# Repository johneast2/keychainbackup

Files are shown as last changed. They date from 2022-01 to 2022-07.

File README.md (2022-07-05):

# keychainbackup



## What is keychainbackup?

Keychain backup is a simple device to create encrypted backups of your files that you take with you on your keychain! Think of it as an offsite backup of your important files, that is always with you. With the added benfit of not having to pay monthly fees.

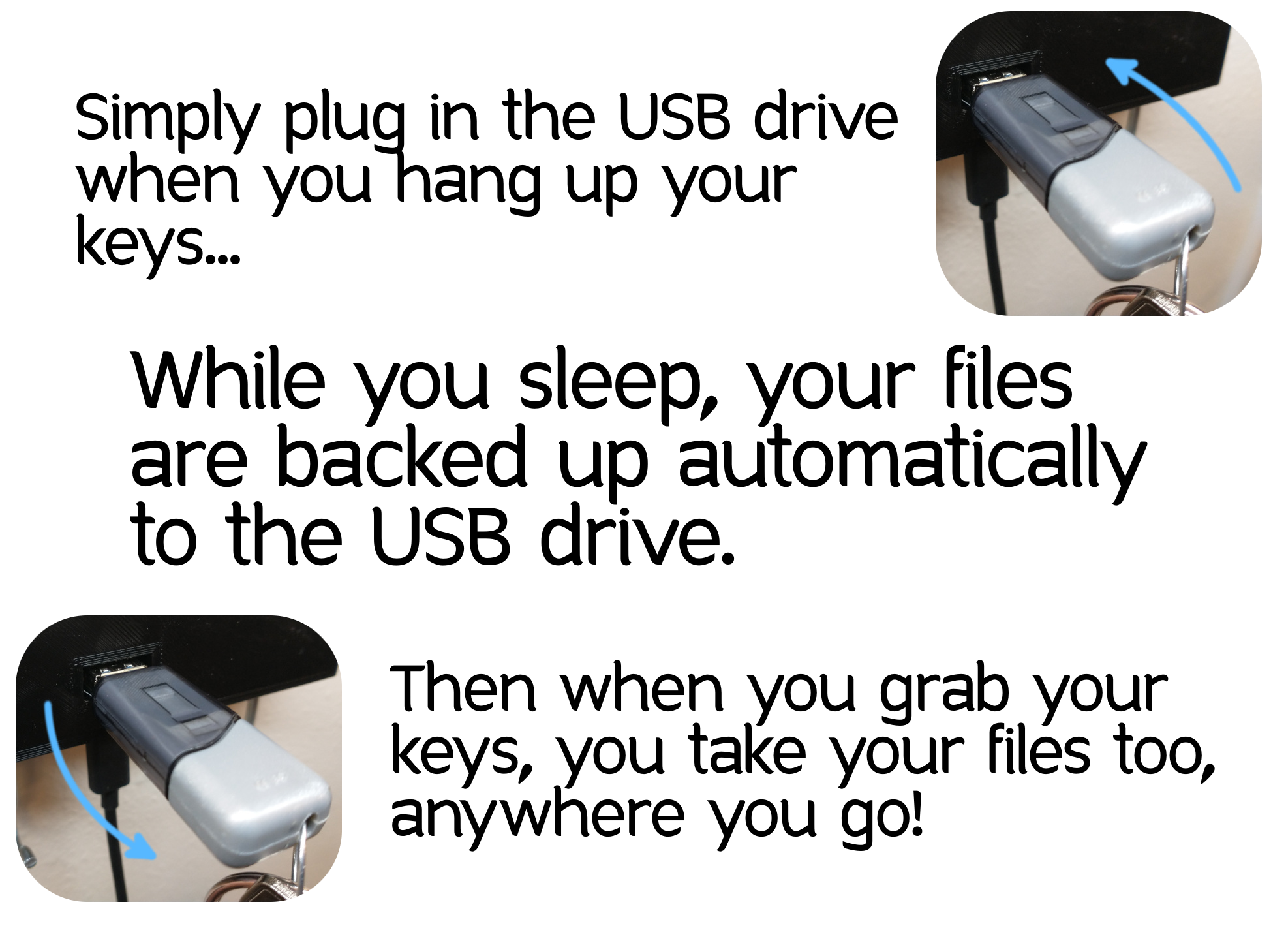
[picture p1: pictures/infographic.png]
infographic


## Example setups

Here's some examples of how to use keychain backup. Personally, I have a linux server that acts as a backup server. My important files from my other computers get backed up to it, then every night it backs up the changed files to the keychain backup. I have it scheduled to stop running the backup early in the morning, to make sure that the USB flash drive can be removed safely.

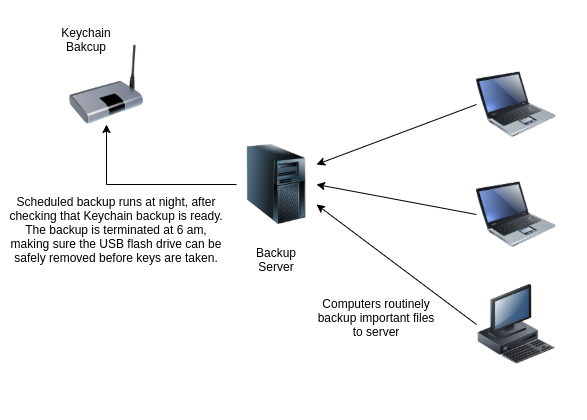
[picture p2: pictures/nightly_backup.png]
nightly backup


Another idea I had was to alternate USB flash drives. That would allow backups to run during the day without an extra backup server.

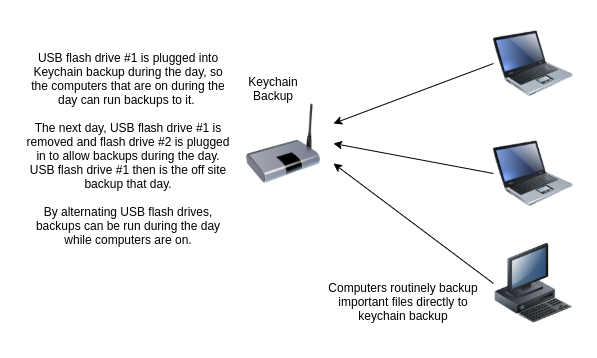
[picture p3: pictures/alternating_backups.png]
Alternating backups


## Questions and Answers

Q: Since I can't do "Safely Remove USB" on my USB drive, won't the filesystem on my USB drive get ruined?

A: It is designed to use the ext4 filesystem, which is a very resisilent. To prove that, I created a test system to mimic unexpectedly removing the USB Drive. It tested 500+ removals and had no failures! You can read about it [here.](docs/TestingResults.md)

## Getting Started

### Raspberry Pi Version

JUN 16 2022 - Still a work in progress. These steps should work to get you setup but there may be bugs! John

### Hardware Setup

Items needed:

1x printed out case - get it [here](case/raspberry_pi_case.stl)

4x m2.5 5mm screws (for mounting the raspberry pi in the case)

3x cup hooks (I used 1.25" Hillman Cup hooks)

2x #8 2.5" screws (for mounting on the wall)

2x drywall screw holders (also for mounting on the wall)

Drill with 1/4" drill bit (for the drywall holder screw holes)

1x Raspberry Pi, setup to connect to your wifi + its power stuff

USB Drive formatted with EXT4 for backing up to.

1. Place the Raspberry Pi in the case and screw it in with the 4x m2.5 screws.

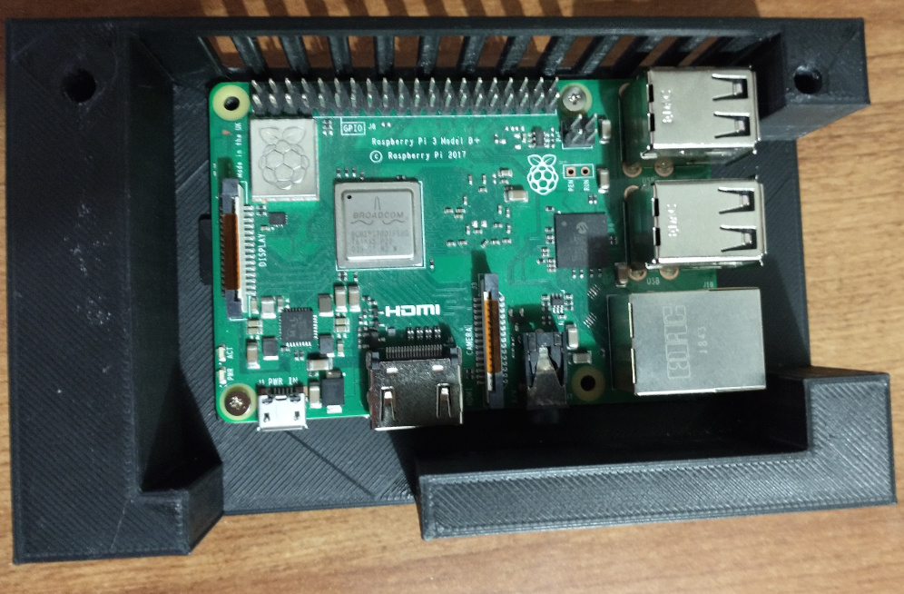
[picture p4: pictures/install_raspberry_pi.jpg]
installing into case


2. Screw in the cup hooks to the bottom of the case.

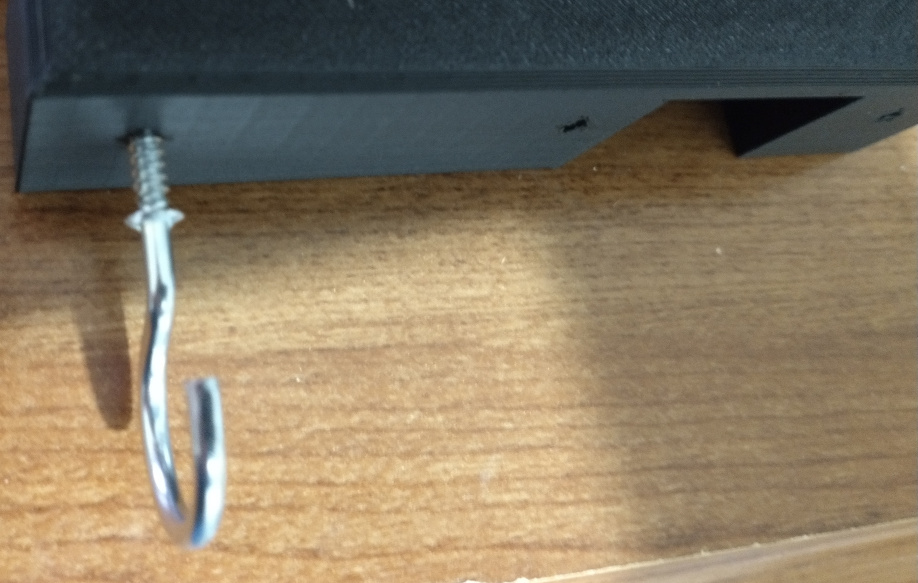
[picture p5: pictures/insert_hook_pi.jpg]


3. Using the case as a guide, drill out 1/4" holes and mount the case with the 2x #8 screws.

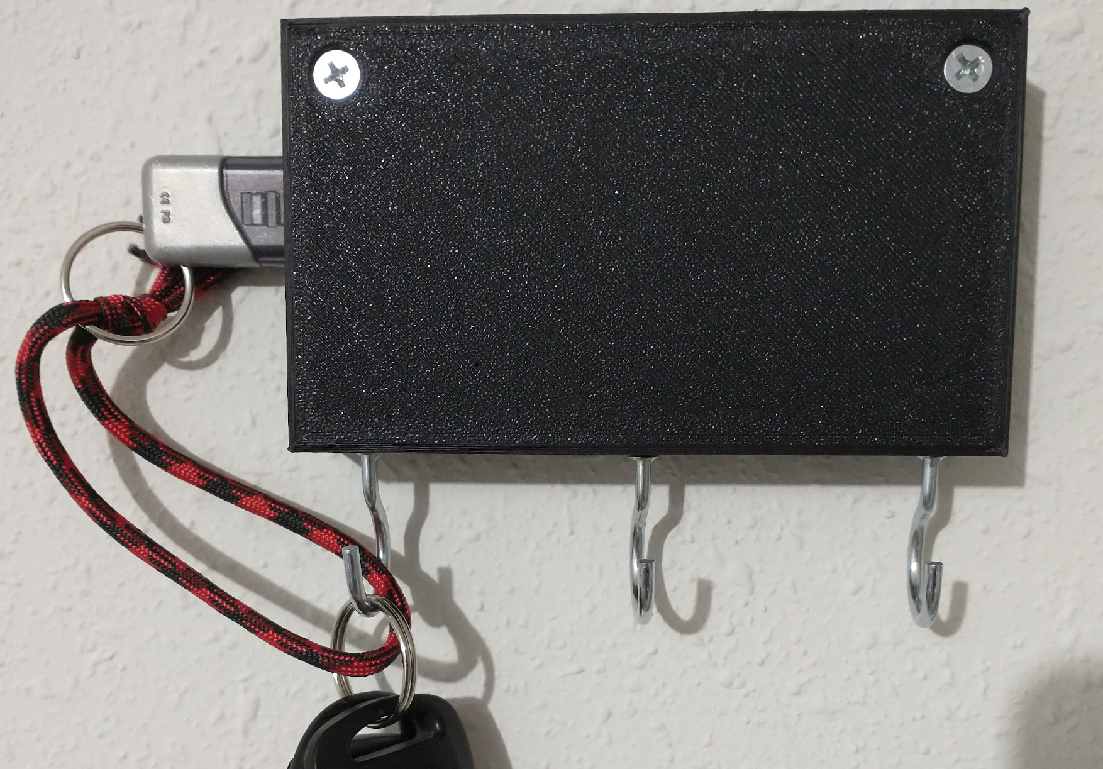
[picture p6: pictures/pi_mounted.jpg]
mounted on wall


4. Plug in the power stuff for the Raspberry Pi and let it turn on.
5. Plug in your USB drive.

### Software Setup

**PLEASE NOTE: This will delete all data on your USB drive!**

1. Remote into the Raspberry Pi using SSH and install cryptsetup: ```sudo apt update``` and ```sudo apt install cryptsetup```
2. Find the device name for your USB drive, run ```mount``` and make note of the ```/dev/sdX``` that represents your USB drive.
3. Run fdisk on that device: ```fdisk /dev/sdX```
4. Delete everything on there: type ```d``` enter then ```n``` enter, and accept all the defaults. Then type ```w``` and press enter.
5. Then setup encryption on that partition, run ```cryptsetup luksFormat /dev/sdX1```, accept the warning by typing in an upppercase ```YES``` and press enter.
6. Enter a password for this encrypted partition, don't forget it!
7. Once that finishes, make a directory to mount the encrypted device at: ```sudo mkdir /mnt/container```
8. create a key to mount the container on boot: ```sudo dd if=/dev/random bs=32 count=1 of=/root/lukskey```
9. Add that key to your encrypted container: ```sudo cryptsetup luksAddKey /dev/sdX1 /root/lukskey```. Enter the container password you setup.
10. Get the UUID for your encrypted parition, run ```sudo blkid``` and find the UUID associated with your encrypted container, you'll need this to setup crypttab.
11. Edit your ```/etc/crypttab``` file with your favorite editor and add this: ```container UUID=<uuid from previous step> /root/lukskey luks```, save and exit
12. Edit your ```/etc/fstab``` file with your favorite editor and add this: ```/dev/mapper/container   /mnt/container  ext4    defaults,nofail,x-systemd.automount 0 0```, save and exit
13. Reboot and verify that the USB drive is automatically mounted on ```/mnt/container```

At this point the Raspberry Pi is setup to automatically mount the encrypted USB device when it is plugged in. Next setup your backup software to backup to the USB device. A howto will be coming shortly!

### Omega2+ version

### Hardware setup

### Items needed: Phillips screwdriver, 1/4" drill bit, drill, anti static wrist strap, and an Omega2+.
 1. Place the circuit board on the case and screw in the 4 m3 screws.

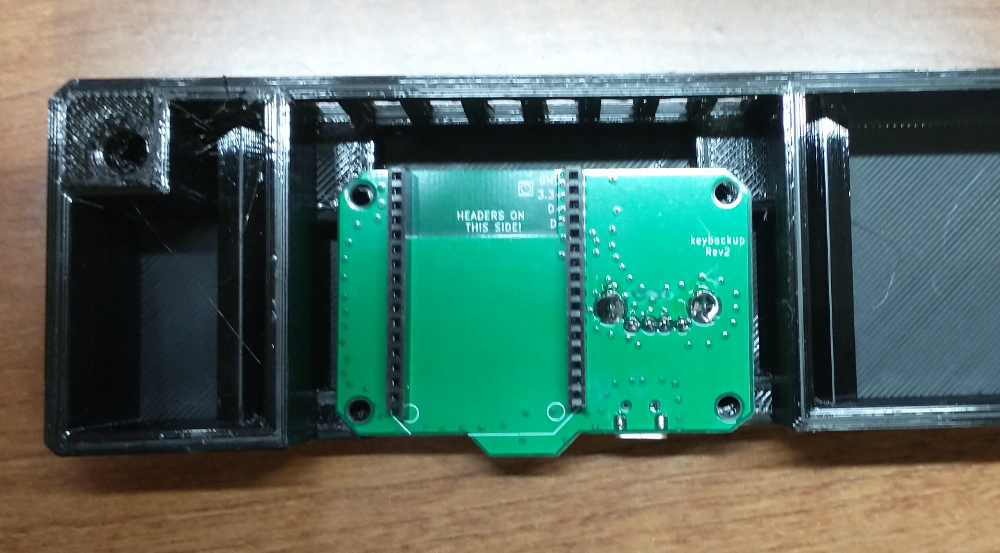
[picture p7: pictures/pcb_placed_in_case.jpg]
PCB in case
 

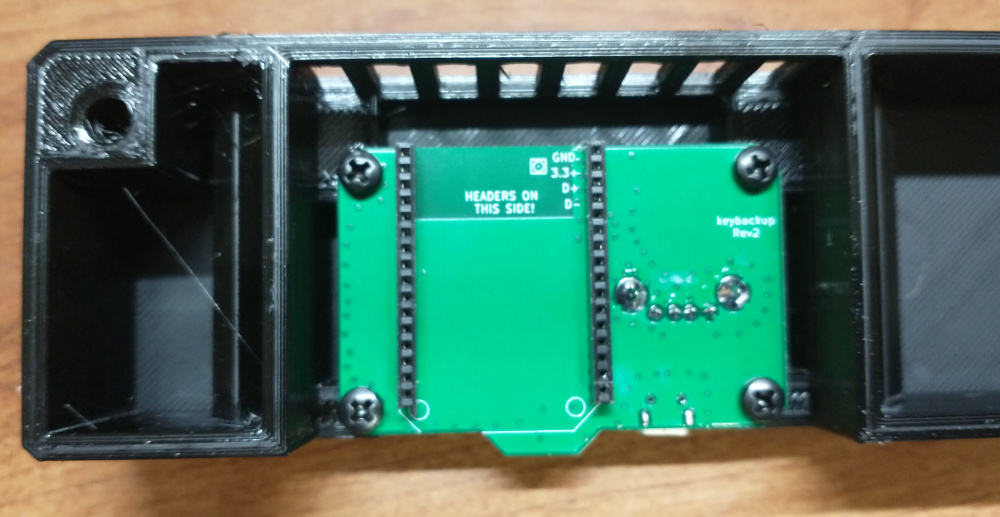
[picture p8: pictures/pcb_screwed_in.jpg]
PCB screwed in
 

 2. Screw in the hooks into the diamond holes on the bottom of the case.

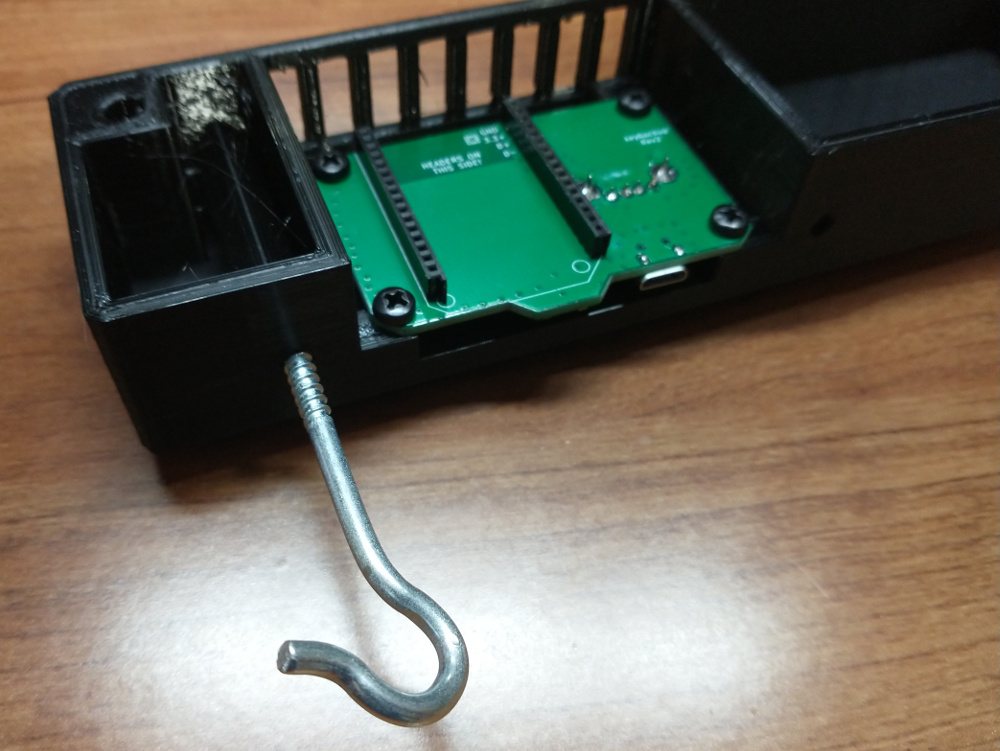
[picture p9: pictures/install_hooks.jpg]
install hooks
 

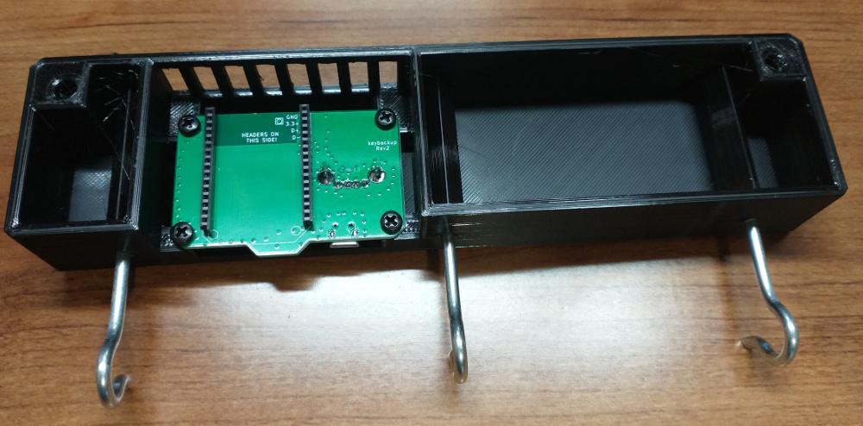
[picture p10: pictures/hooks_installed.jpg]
hooks installed
 

 3. Insert the Omega2+ into the headers on the circuit board.

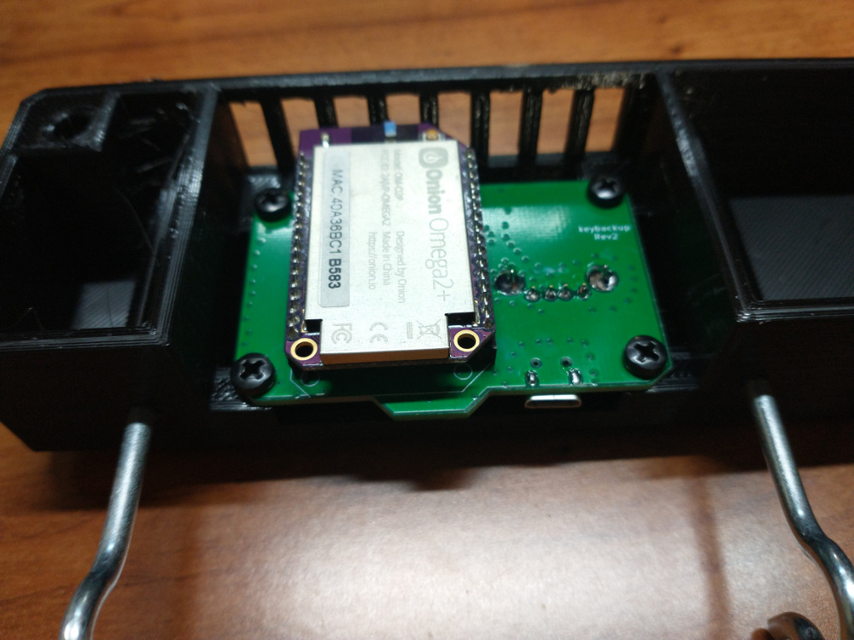
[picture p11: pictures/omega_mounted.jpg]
omega2+ mounted
 
 
 4. To mount the device on the wall, drill two 1/4" holes, using the case as a guide. Insert the blue drywall hangars into the holes. Then use the provided silver screws to screw the case to the wall.

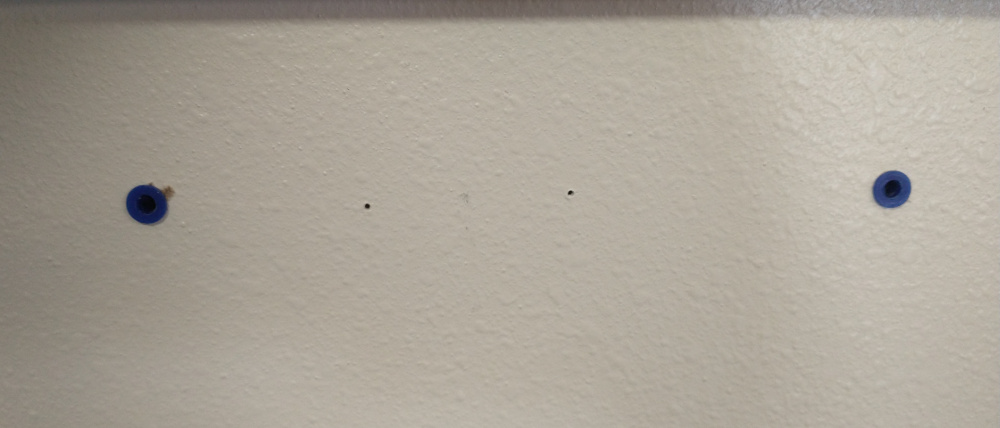
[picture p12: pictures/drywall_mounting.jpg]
drywall hangars
 
 
 5. Insert the USB drive into the USB port. <b>NOTE: The initial setup will erase all files on the USB drive!</b>
 
 6. Plug in the micro usb connector on the circuit board, then insert the other end into the power brick and plug it in to power on the device.

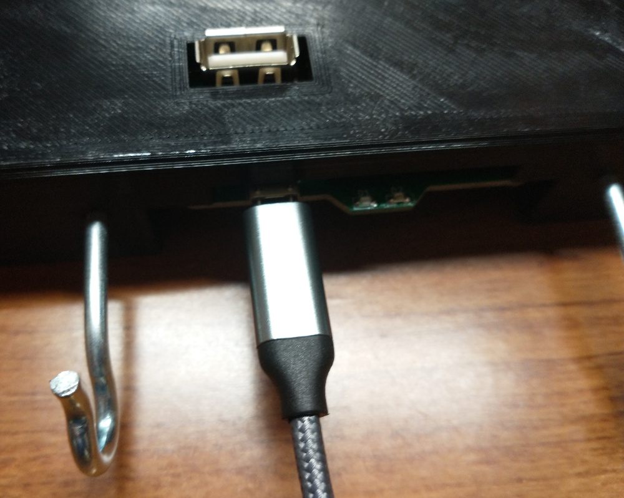
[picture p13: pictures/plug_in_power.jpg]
plug in microusb
 

## Software Setup

 1. Go through Omega setup, [https://docs.onion.io/omega2-docs/first-time-setup.html](https://docs.onion.io/omega2-docs/first-time-setup.html)
 2. Start the Setup app. [Get it here!](https://github.com/johneast2/keychainbackup/releases/tag/V1.1)
 3. Enter the Omega2+'s Ip address.
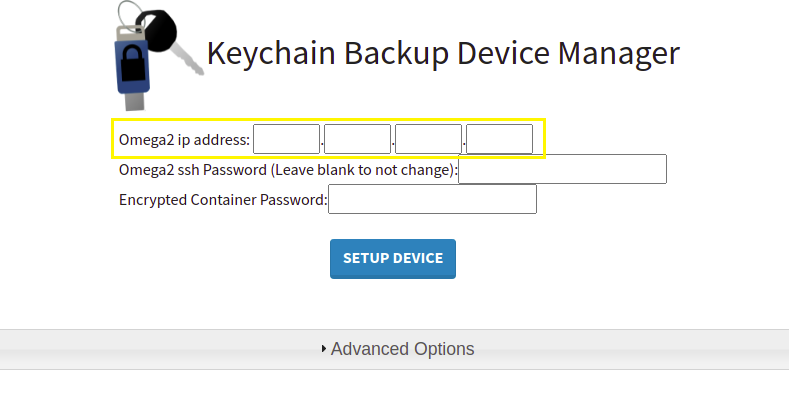
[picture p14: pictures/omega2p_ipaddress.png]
Omega2p IP address spot
 
 4. Set a new SSH password the Omega2+.
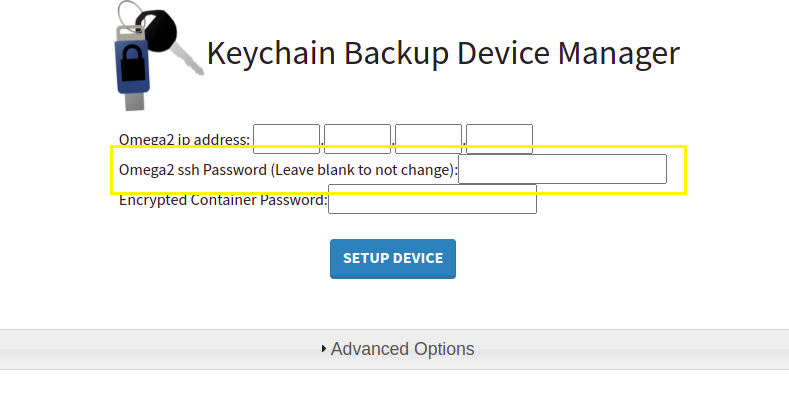
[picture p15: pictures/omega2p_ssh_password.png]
Omega2p ssh password
 
 6. Set the password that will be used for the encrypted storage container.
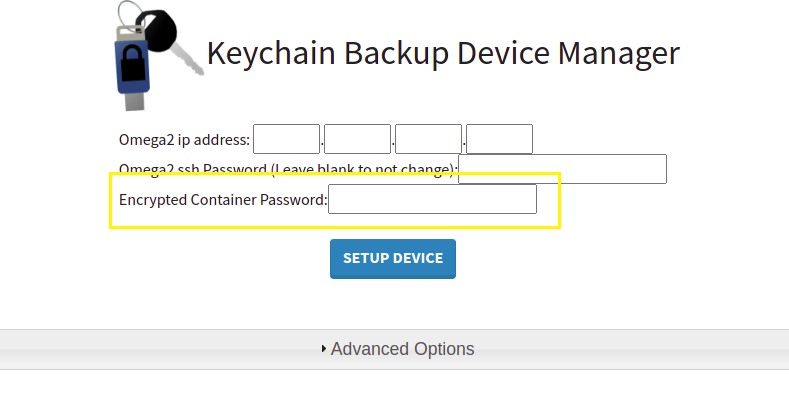
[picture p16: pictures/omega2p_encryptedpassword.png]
Omega IP address spot
 
 7. If you want to use Syncthing, click advanced, then make sure Install Syncthing checkbox is checked.
 8. Click setup device.
 9. You will need to click the warning button about all files being deleted from the USB drive.
 10. Once setup finishes, the encrypted storage container will be mounted at /tmp/container on the Omega2+.

With the keychain backup device setup, next is setting up a backup program to backup to it. Any backup program that can send data to an SSH host should be able to work with keychain backup. [Here's an example using a free, open source program](docs/SettingUpBackups.md)

Keychain Backup now supports Syncthing! For info on setting it up, check out the [Syncthing Documentation!](docs/SettingUpSyncthing.md)

## Limitations

While this is a cool backup device, there are some limitations to be aware of. It's mostly designed to be used as a cold storage type device, where data is backed up to it that isn't changing often.

1. Backup speed is not fast. The fastest I've been able to backup data to it is about 1GB in 15 minutes. Assuming 1GB every 15 minutes, if the device is plugged in over night for 8 hours, it could backup 32GB.
2. Its backing up on a solid state USB device. Backing up constantly changing data will probably shorten the lifetime of the USB device.
3. The encryption key is stored on the device on your wall. If someone gets access to it, they will be able to decrypt all the data on the USB device. The encryption is designed to prevent some random person from viewing your photos and it probably won't stop someone who is determined to get access to it.

## File Recovery.

For information on recovering files from the USB drive, [see this document.](docs/RecoveringFiles.md)

## Building the manager app

You will need nodjes and npm isntalled.

Install electron-packager: ```npm install --save-dev electron-packager```

Then to build it for windows: ```npx electron-packager manageApp/ keybackupmanager --platform=win32 --arch=x64```

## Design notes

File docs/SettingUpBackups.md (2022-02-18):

# Setting up backups with Duplicati to Keychain Backup

Duplicati is a free, opensource backup application, avaible for Windows, Linux and MacOS. It supports connecing to SSH hosts, and scheduling backups, among other features.

1. Download Duplicati and install it. Download from here: [Duplicati 2.0](https://www.duplicati.com/download)

2. Open Duplicati by double clicking on the Duplicati 2 Desktop icon or by right clicking on the tray icon and selecting Open

3. At the Duplicati main window click Add Backup on the left side of the window.

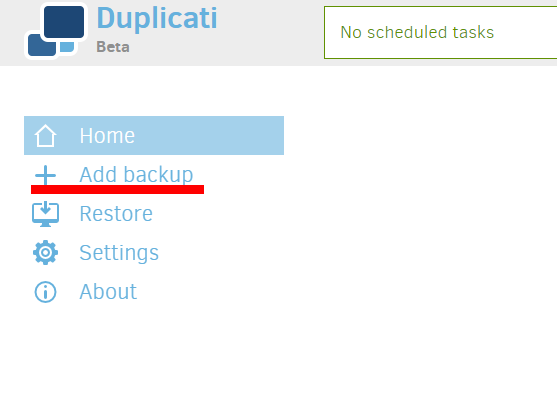
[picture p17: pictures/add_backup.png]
Main_Window


4. At the Add a new backup screen make sure Configure a new backup is selected, then click Next.

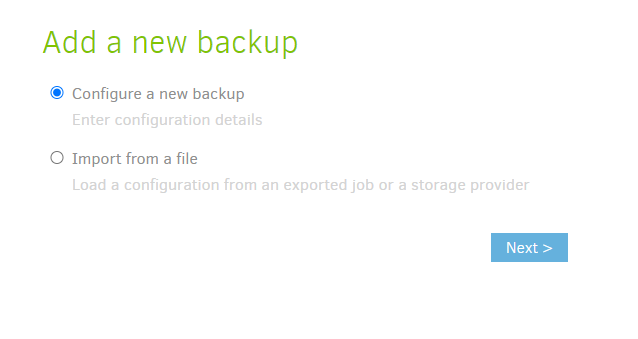
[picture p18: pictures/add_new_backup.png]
new backup


5. At the General backup settings screen, give the backup a descriptive name. Then set Encryption to No encryption. Because all files backed up on the keychain backup device are encrypted already, duplicati's encryption is unnecessary. Click Next to continue.

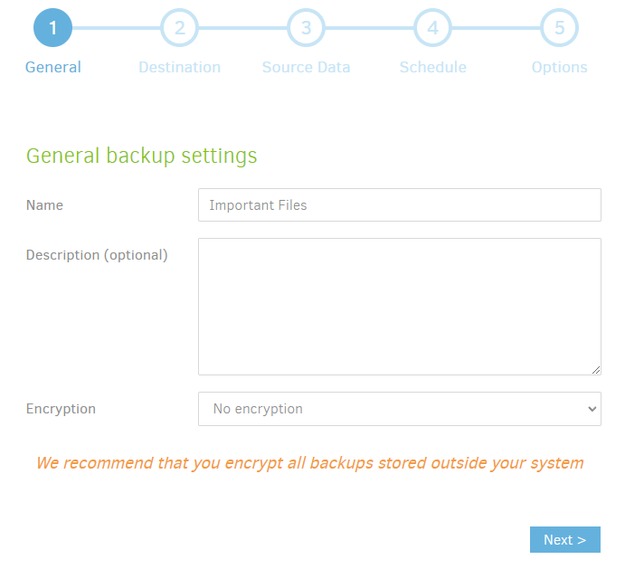
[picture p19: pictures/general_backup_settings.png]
general backup settings


6. At the Backup destination screen, change Storage Type to ```SFTP(SSH)```

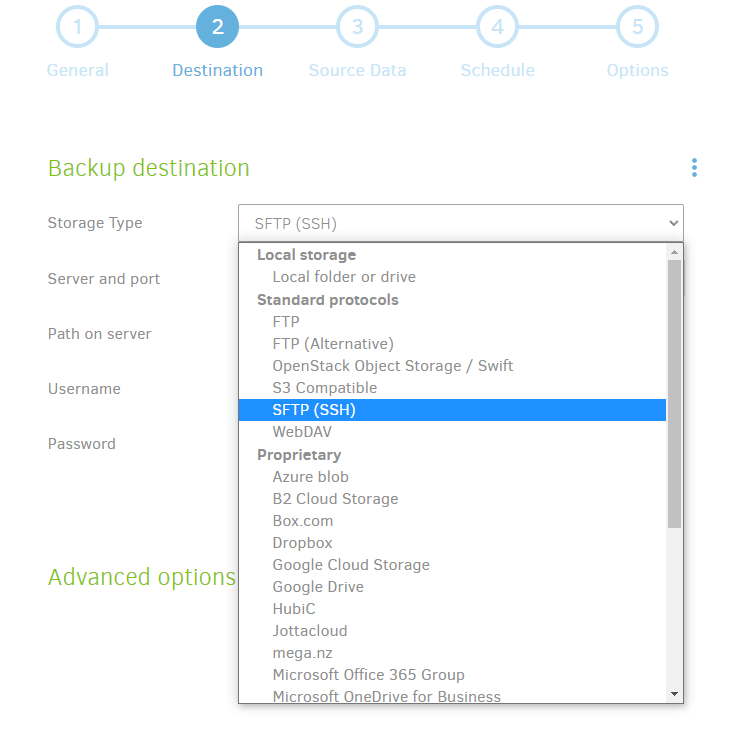
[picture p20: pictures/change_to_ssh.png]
change to ssh


7. Enter the ip address of your keychain backup device, then enter ```2222``` for the Port. 
8. For Path on server enter ```/root/encrypted_container/```
9. For Username, enter ```root```
10. For Password, enter the password you chose during the device setup.

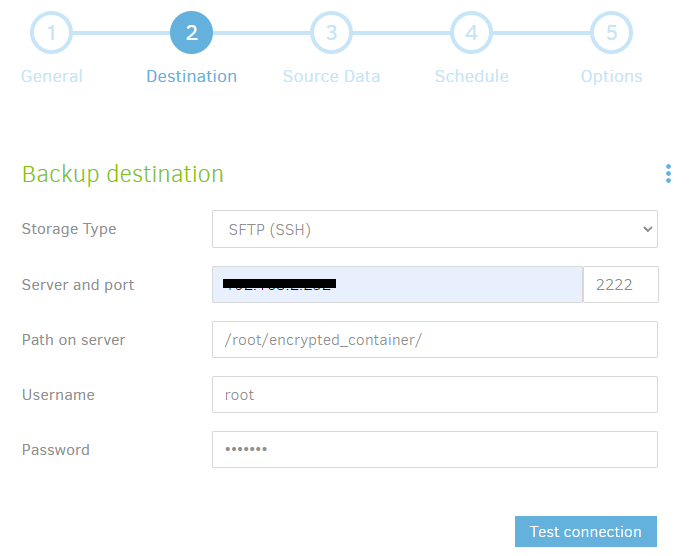
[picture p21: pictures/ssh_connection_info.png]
ssh connection info


11. Then click the Test connection button at the bottom. There will be a pop up window asking if you want to trust the host certificate. Click Yes.

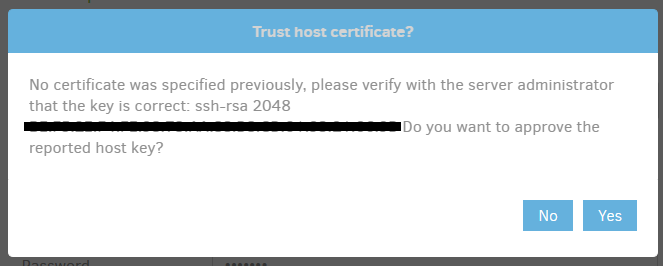
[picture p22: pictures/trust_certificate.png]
trust_certificate


12. If Duplicati is able to connect to the keychain backup device, there will be a pop up window showing Success, click OK.

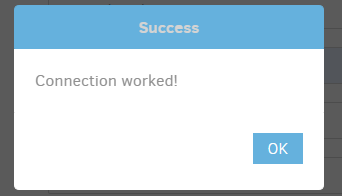
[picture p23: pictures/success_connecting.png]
success_connecting


13. Then click Next to continue. At the Source data screen, select the folders that should be backed up. Then click Next.

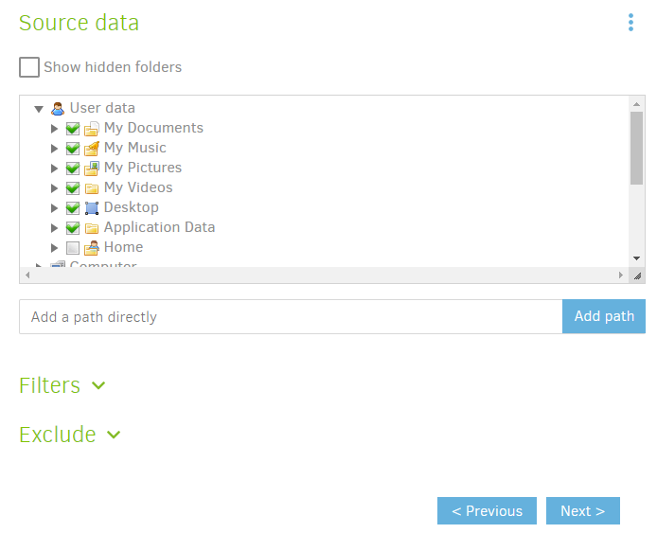
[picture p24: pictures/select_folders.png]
select_folders


14. At the Schedule screen, make sure Automatically run backups is checked and specify the times that the backup should be run. Consider the most likely times
for the usb drive to inserted in the keychain backup device. Once finished, click Next.

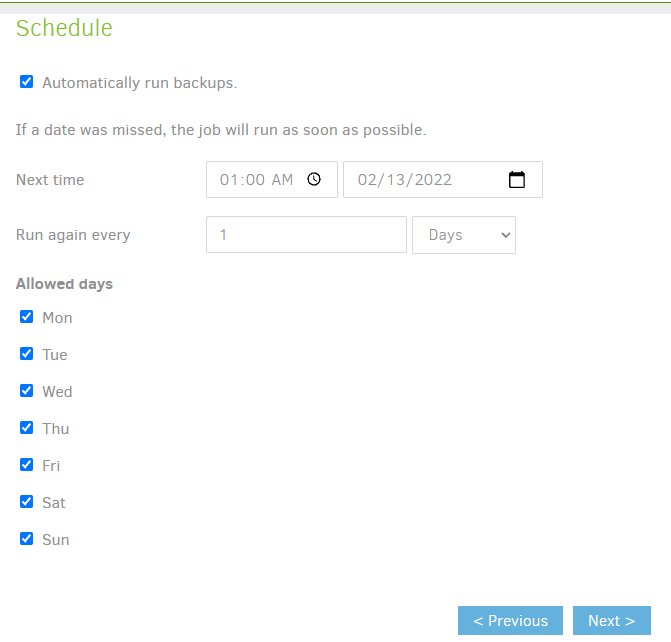
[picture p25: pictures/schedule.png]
schedule


15. On the General options screen, change Backup retention to Smart backup retention. Then click Save.

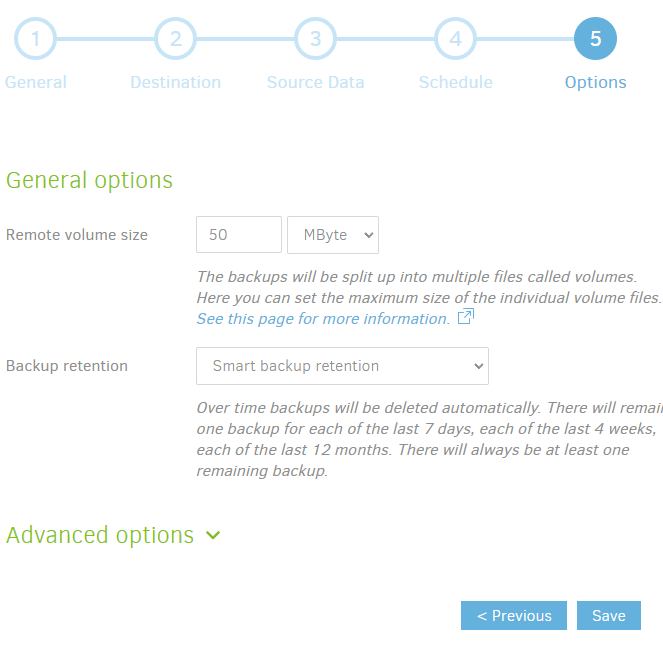
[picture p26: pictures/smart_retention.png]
smart_retention


16. You will see a warning message about ```No encryption```, which doesn't matter in this case, because
the files are being backed up to an ecrypted container. Click Continue without encrytion.

Congratulations! You've successfully setup scheduled backups to your encrypted keychain backup device!

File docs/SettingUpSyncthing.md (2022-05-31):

# Setting up Syncthing to run on Keychain Backup

Syncthing is a free and open source program to allow you to synchronize your files between 2 or more computers. Find out about it by checking out its website: [https://syncthing.net/](https://syncthing.net/)

## Setup using the manage app:

1. When setting up the keychain backup device, click advanced, then make sure Install Syncthing checkbox is checked.
2. After the setup is finished, you can access syncthing's webpage by going to <Omega2+'s ip address>:8384. NOTE: By default there will be no username or password setup to protect syncthing's config webpage. Please set that up!

## Manual setup:

1. Download Synthing from our github repo: [Sything v1.20.1](../syncthing)
    
    NOTE: This is the syncthing mipsle binary downloaded from [Syncthing's Download page](https://github.com/syncthing/syncthing/releases/download/v1.20.1/syncthing-linux-mipsle-v1.20.1.tar.gz), then shrunk using ```upx```. You can use the one from syncthing yourself, you'll just have to use ```upx``` to shrink it because its too big for the omega2+'s storage space.

2. Use your favorite scp program to copy it to the /root/ folder on the omega2+.

3. Reboot the keychain backup device. It will automatically find the sycnthing binary and start it after mounting the encrypted USB drive.

4. You can access syncthing's webpage by going to <Omega2+'s ip address>:8384. NOTE: By default there will be no username or password setup to protect syncthing's config webpage. Please set that up!

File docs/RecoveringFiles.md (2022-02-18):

# Recovering Files Using Duplicati

Because of how the files are encrypted on the USB Drive, simply popping it into the USB port of your Windows computer will not work. Here are the steps for recovering your files if you used Duplicati to back them up.

1. Plug the USB drive into the Omega2+. Make sure the Omega2+ is powered on.

2. Open duplicati by double clicking on the Duplicati 2 Desktop icon or by 
right clicking on the tray icon and selecting Open.

3. On the main screen, click on Restore on the left side.

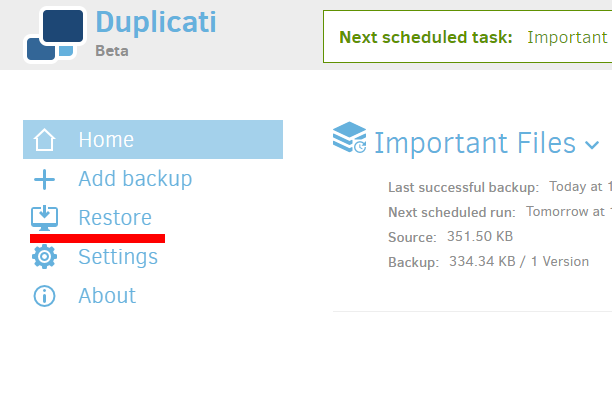
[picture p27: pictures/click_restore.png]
click_restore


4. On the Where do you want to restore from screen click on the name of the backup configuration that you want to restore from.
In this case, the backup configuration was named Important Files when it was setup, so that is selected.
Then click Next.

5. At the Select Files screen, select the files and folders you want to restore and click Continue.

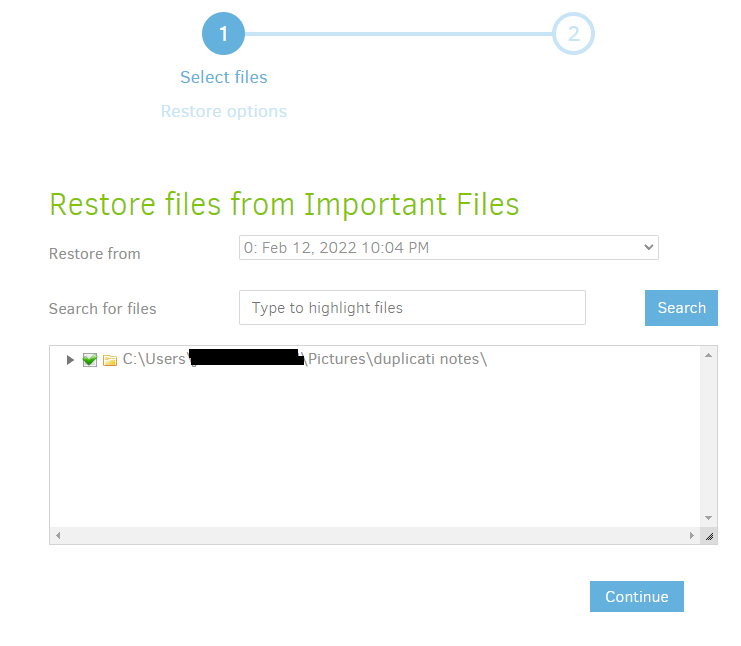
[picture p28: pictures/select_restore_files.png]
select_restore_files


6. At the Restore Options screen, pick either to restore to the Original location or Pick location and specify a location.
Then click Restore.

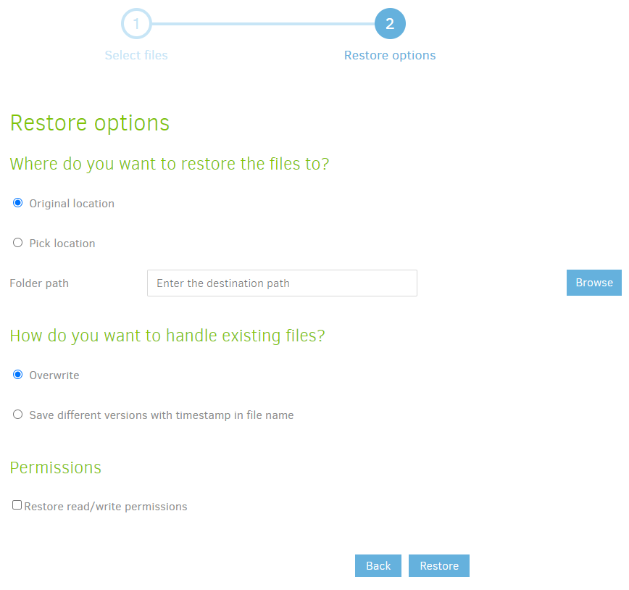
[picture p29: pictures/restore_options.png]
restore_options


7. Once the files have been restored, click OK.

# Recovering Files Using WinSCP

Because of how the files are encrypted on the USB Drive, simply popping it into the USB port of your Windows computer will not work. Here are the steps to use WinSCP to copy off your backup files from the USB drive.

  1. Plug the USB drive into the Omega2+. Make sure the Omega2+ is powered on.
  2. Download WinSCP from here: [WinSCP Download page](https://winscp.net/eng/download.php) and install it.
  3. Open WinSCP, you'll see this window on startup:
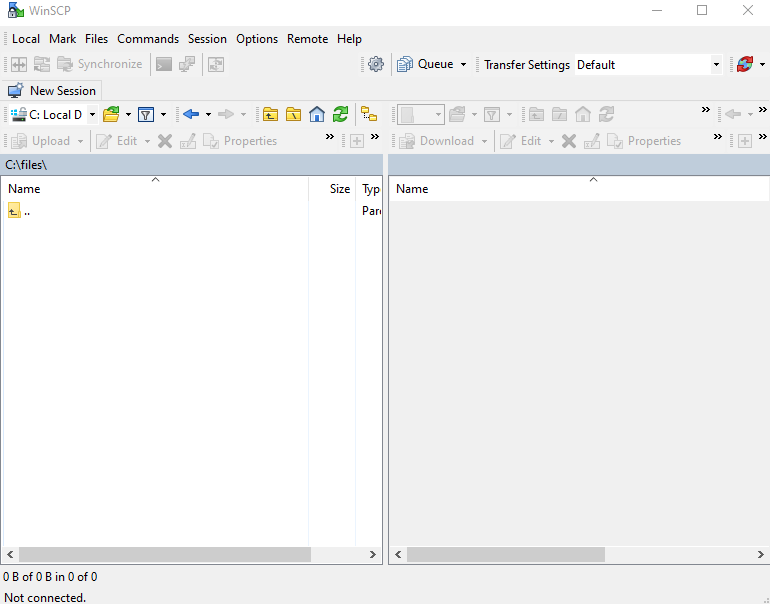
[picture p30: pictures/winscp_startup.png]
WinSCP initial window
  
  3. Click on the New Session button:

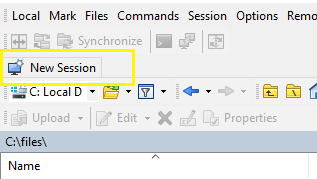
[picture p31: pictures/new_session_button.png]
new session button
  
  
  4. The New session screen will appear. In the Host Name field, enter the ip address of the Omega2+. Port Number leave at 22. The Username is root and the Password is the SSH password that was entered at setup.
  
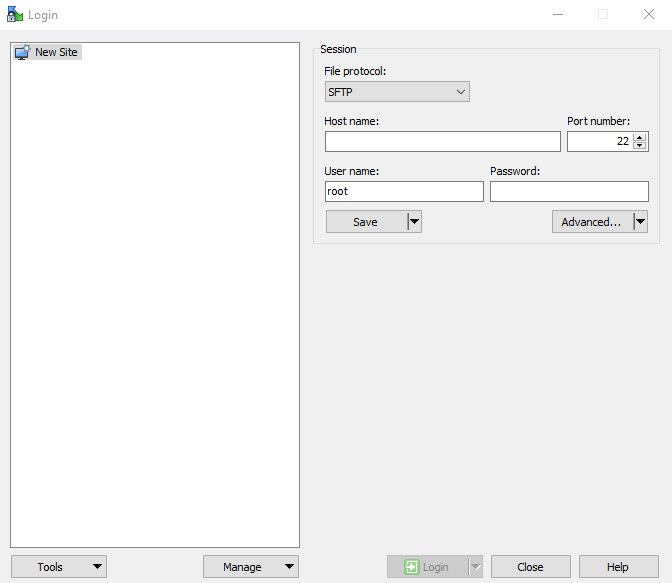
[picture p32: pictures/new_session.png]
new session window
  
  
  5. Click the login button. If this is the first time connecting to the omega2+, you will get a warning about adding an unknown servers key, its ok. Click on the Yes button.
  
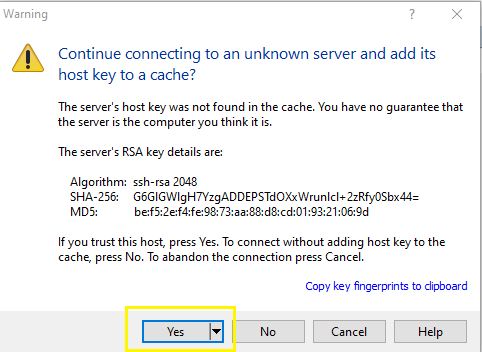
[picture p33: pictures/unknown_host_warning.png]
unknown host warning
  
  
  6. After successfully connecting, the window will show the files on the Omega2+ on the right window pane. The left window pane is the local computer files.
  7. In the right window pane, double click on the encrypted_container folder to access the backed up files on the Omega2+. 
  8. To copy the files back to the local computer, drag the folders/files from the right pane to the left pane. For example, In the following picture, it shows the folder SuperImportantFiles. To download that folder to my computer, I would select that folder then drag it over into the right window pane.
  
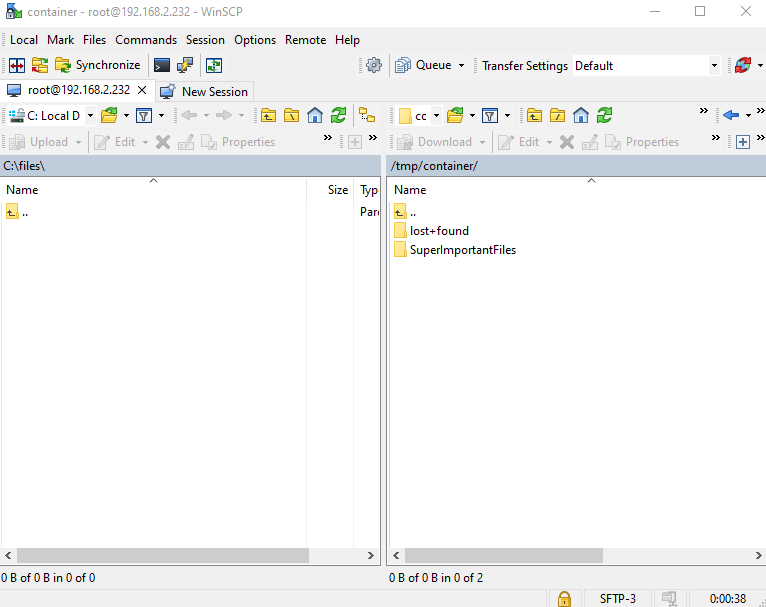
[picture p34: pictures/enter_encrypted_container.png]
example files to restore
  
  
  Then a window will show up, showing the progress of the copy.
  
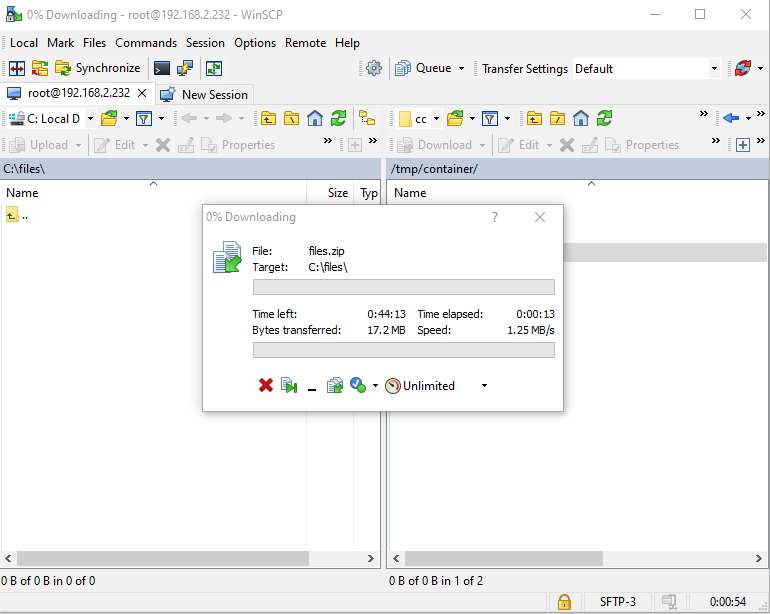
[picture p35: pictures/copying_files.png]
copying files over
  
  
  9. Once the copy operation has finished, the files are available on the local computer.

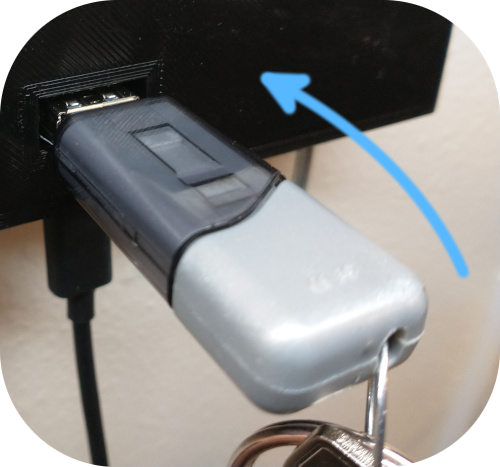
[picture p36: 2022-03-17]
pictures/pluginbluearrow.png

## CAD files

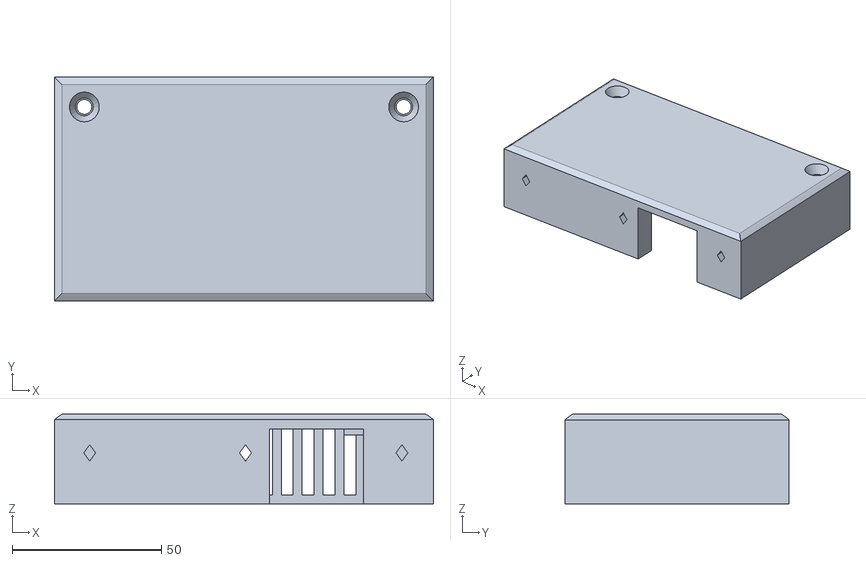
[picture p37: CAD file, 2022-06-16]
case/raspberry_pi_case.stl
127.0 x 75.0 x 30.0

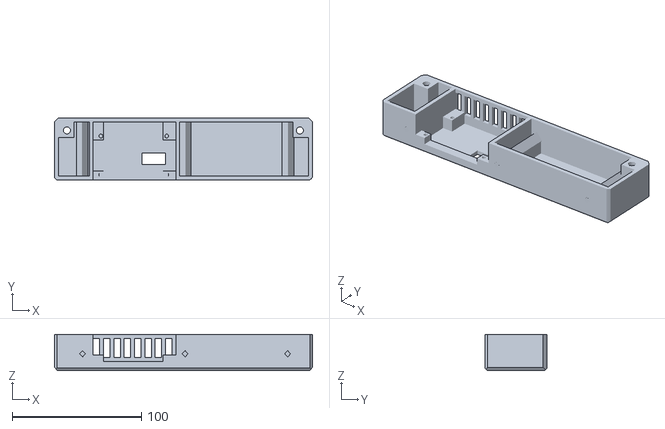
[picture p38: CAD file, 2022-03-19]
case/vented case with 3 vertical hooks.stl
200.0 x 48.0 x 28.0

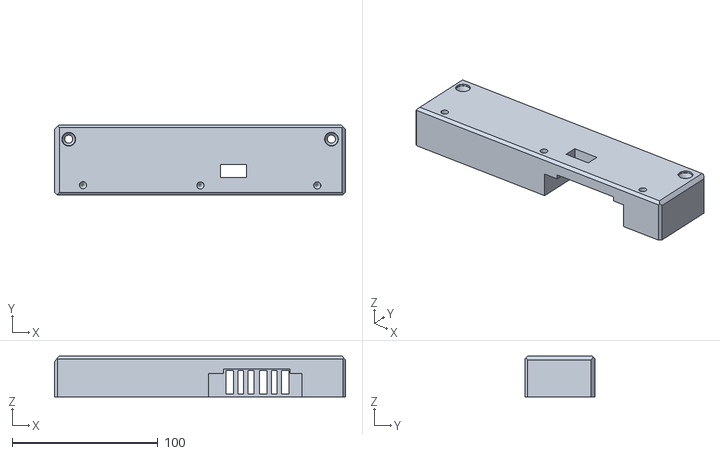
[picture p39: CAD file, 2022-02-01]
case/vented case with 3 hooks.stl
200.0 x 48.0 x 28.0

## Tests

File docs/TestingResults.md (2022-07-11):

# Testing Interrupted Backups

Since there's no way to "Safely Remove USB" option on keychain backup, it's extremely important that 
removing the USB drive doesn't break the filesystem on the USB drive. It is designed to use the ext4 filesystem, so it should be very resisilent.
But its always good to test assumptions :).

To test that the USB drive's filesystem won't be affected by being removed repeatedly, 
I made a test system using a nodeMCU and an a relay. The nodeMCU controls the relay and connected to the wifi network.
I hacked up a USB extension cable and put the relay between the + voltage line. That way I can control the power to the USB drive 
and mimic an unexpected removal. 

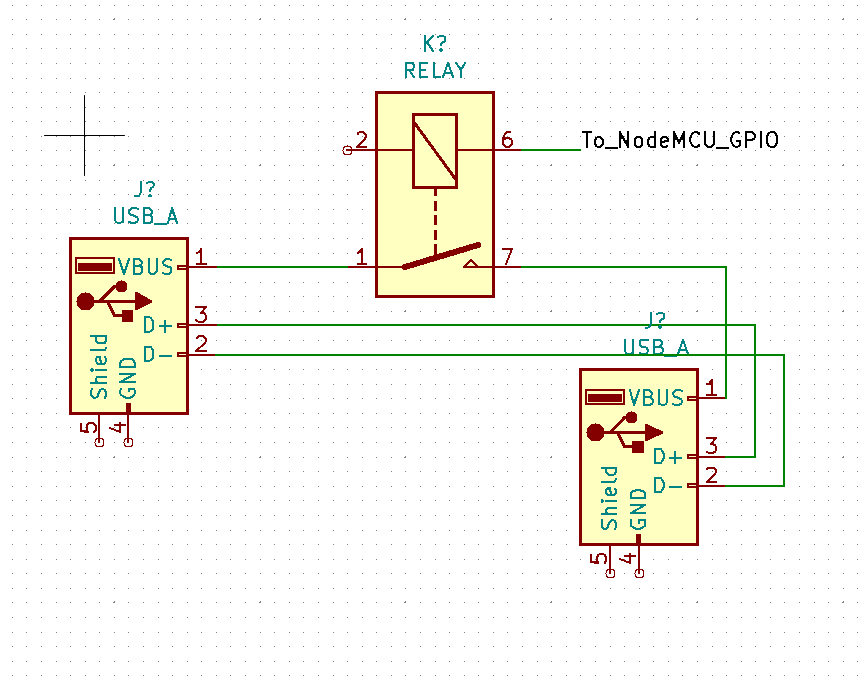
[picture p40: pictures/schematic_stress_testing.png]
schematic


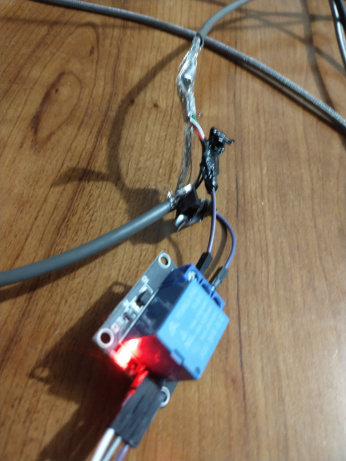
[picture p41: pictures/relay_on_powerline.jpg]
relay on power line


I wrote a simple program that checks if the keychain backup device is on, then powers on the USB 
drive and makes sure the encrypted volume mounts successfully. It then starts an rsync backup to the device and waits a few minutes.
Finally it sends a command over the network to the nodeMCU to power off the USB drive. Then repeat over and over, until the 
USB drive is corrupted.

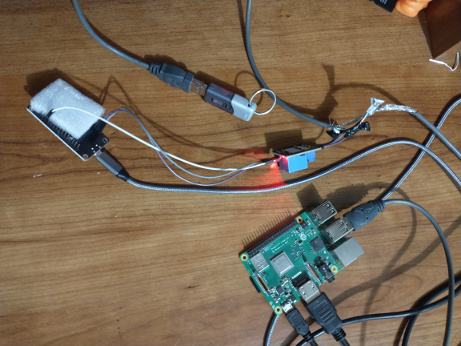
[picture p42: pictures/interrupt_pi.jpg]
raspberry pi getting tested


# Results

I tested against the omega2+ and the Raspberry pi versions of keychaing backup. Both ran for more than 500+ interrupted backups without failing the test.
I never saw any filesystem corruption on the USB drive filesystem.

With those kinds of results, I am extremely confident that removing the USB drive without "Safely Removing USB" will not have an adverse effect on the USB drive.

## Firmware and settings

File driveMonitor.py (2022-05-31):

import os
from enum import Enum
import time
import subprocess
from subprocess import Popen, PIPE

import onionGpio3



passwordFile = "/root/containerPassword.txt"
containerFile = "/mnt/sda1/container.bin"

syncthingCommand = "/root/syncthing --gui-address=0.0.0.0:8384 > /dev/null 2>&1 &"

containerMountTimeLimitSeconds = 60

class DriveState(Enum):
    NO_USB_DRIVE = 1
    USB_DRIVE_MOUNTED = 2
    NO_CONTAINER = 3
    CONTAINER_MOUNTED = 4
    CONTAINER_ERROR = 5
    NO_CONTAINER_PASSWORD = 6

def driveIsMounted():
    mountCheckResult = ''

    mountCheckResult = subprocess.run(['mount'], stdout=subprocess.PIPE, universal_newlines=True)

    if "container" in mountCheckResult.stdout:
        return True
    
    return False

def afterMountedSetup():
    if not os.path.isdir('/root/encrypted_container'):
        process = subprocess.run("ln -s /tmp/container/ /root/encrypted_container", shell=True)
    process = subprocess.run("dropbear -P /var/run/dropbear2.pid -p 2222 -K 300 -T 3", shell=True)

def checkDriveState(driveStateParam):

    if not os.path.isfile(passwordFile):
        return DriveState.NO_CONTAINER_PASSWORD

    # check if the drive is already mounted:
    if driveStateParam != DriveState.CONTAINER_MOUNTED and driveIsMounted():
        driveStateParam = DriveState.CONTAINER_MOUNTED
        afterMountedSetup()
        return driveStateParam
        

    sdaCheckResult = ''

    sdaCheckResult = subprocess.run(['ls', '/dev'], stdout=subprocess.PIPE, universal_newlines=True)

    if not "sda1" in sdaCheckResult.stdout:
        if driveStateParam != DriveState.NO_USB_DRIVE:
            # got unplugged...
            # just do a reboot for now?
            # needed because dev mapper will allow it to continue to be written too even
            # though the disk is gone
            subprocess.run(['reboot'])
        return DriveState.NO_USB_DRIVE
    elif driveStateParam == DriveState.NO_USB_DRIVE:
        driveStateParam = DriveState.USB_DRIVE_MOUNTED

    if driveStateParam == DriveState.USB_DRIVE_MOUNTED and not os.path.isfile(containerFile):
        return DriveState.NO_CONTAINER

    if driveStateParam == DriveState.USB_DRIVE_MOUNTED or driveStateParam == DriveState.NO_CONTAINER and os.path.isfile(containerFile):
        #get the password
        containerPassword = ""
        with open(passwordFile) as passwordFileHandle:
            containerPassword = passwordFileHandle.readline().rstrip()

        #attempt to mount the container
        process = subprocess.run("mkdir /tmp/container", shell=True)

        process = Popen(["cryptsetup", "luksOpen", containerFile, "container"], stdin=PIPE)
        process.communicate((containerPassword + "\n").encode("ascii"))
        process.wait()

        time.sleep(5)

        process = subprocess.run("mount /dev/mapper/container /tmp/container/ && sleep 5", shell=True)

        #actually check if the conatiner mounted

        if driveIsMounted():
            afterMountedSetup()
            driveStateParam = DriveState.CONTAINER_MOUNTED

        else:
            driveStateParam = DriveState.CONTAINER_ERROR

    return driveStateParam


def main():
    gpio19Green = onionGpio3.OnionGpio(19)
    gpio18Red = onionGpio3.OnionGpio(18)

    # turn on the green gpio, show its on
    gpio19Green.setOutputDirection(1)

    # turn off the red gpio
    gpio18Red.setOutputDirection(0)

    currentDriveState = DriveState.NO_USB_DRIVE

    mountWaitTimerSeconds = -1

    while True:

        currentDriveState = checkDriveState(currentDriveState)

        driveStatePath = '/tmp/driveState.txt'
        driveStateFile = open(driveStatePath, 'w')

        driveStateFile.write(currentDriveState.name)

        if currentDriveState == DriveState.CONTAINER_ERROR or currentDriveState == DriveState.NO_CONTAINER_PASSWORD:
            gpio18Red.setOutputDirection(1)
        else:

            if currentDriveState == DriveState.NO_CONTAINER and mountWaitTimerSeconds == -1:
                mountWaitTimerSeconds = 0
            elif currentDriveState != DriveState.NO_CONTAINER and mountWaitTimerSeconds != -1:
                mountWaitTimerSeconds = -1
            elif currentDriveState == DriveState.NO_CONTAINER and mountWaitTimerSeconds != -1:
                mountWaitTimerSeconds = mountWaitTimerSeconds + 1

            if currentDriveState == DriveState.CONTAINER_MOUNTED:
                if os.path.exists("/root/syncthing"):
                    procs = subprocess.run(['ps'], stdout=subprocess.PIPE, universal_newlines=True)
                    if "syncthing" not in procs.stdout:
                        # syncthing bin is there but not running start it up
                        subprocess.run(syncthingCommand, shell=True)

            if currentDriveState == DriveState.NO_CONTAINER and mountWaitTimerSeconds > containerMountTimeLimitSeconds:
                gpio18Red.setOutputDirection(1)
            else:
                gpio18Red.setOutputDirection(0)

        time.sleep(1)


if __name__ == "__main__":
    main()

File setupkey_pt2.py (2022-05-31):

import os
import time
import subprocess
from subprocess import Popen, PIPE
import sys, getopt

passwordFile = "/root/containerPassword.txt"

def main(argv):

    try:
        opts, args = getopt.getopt(argv,"s")
    except getopt.GetoptError:
        print ('setupkey_pt2.py optional: -s')
        sys.exit(2)

    for opt, arg in opts:
        if opt == '-s':
            print("installing syncthing...")
            process = subprocess.run("mv /root/tempsetupfiles/syncthing /root/ && chmod +x /root/syncthing", shell=True)

    process = subprocess.run("umount /dev/sda1", shell=True)

    process = subprocess.run("mkfs.ext4 -F /dev/sda1", shell=True)

    process = subprocess.run("mkdir /tmp/usb", shell=True)

    process = subprocess.run("mount /dev/sda1 /tmp/usb", shell=True)

    diskspace = subprocess.getoutput("df | grep sda | awk '{print $4}'")
    print("diskspace: " + diskspace)

    process = subprocess.run("dd if=/dev/zero of=/tmp/usb/container.bin bs=1 count=0 seek=" + diskspace + "k", shell=True)

    with open(passwordFile) as passwordFileHandle:
        containerPassword = passwordFileHandle.readline().rstrip()

    process = subprocess.run("mkdir /tmp/container", shell=True)

    process = Popen(["cryptsetup", "-q", "luksFormat", "/tmp/usb/container.bin", ], stdin=PIPE)
    process.communicate((containerPassword + "\n").encode("ascii"))
    process.wait()

    process = Popen(["cryptsetup", "luksOpen", "/tmp/usb/container.bin", "container"], stdin=PIPE)
    process.communicate((containerPassword + "\n").encode("ascii"))
    process.wait()

    process = subprocess.run("mkfs.ext4 /dev/mapper/container", shell=True)

    process = subprocess.run("mount /dev/mapper/container /tmp/container", shell=True)

    process = subprocess.run("cp /root/tempsetupfiles/driveMonitor.py /root/", shell=True)

    process = subprocess.run("cp /root/tempsetupfiles/onionGpio3.py /root/", shell=True)

    process = subprocess.run("cp /root/tempsetupfiles/rc.local /etc/rc.local", shell=True)

    process = subprocess.run("python3 /root/driveMonitor.py &", shell=True)

    process = subprocess.run("rm -rf /root/tempsetupfiles", shell=True)

if __name__ == "__main__":
    main(sys.argv[1:])

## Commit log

2021-12-22 Update driveMonitor.py
    spelling fixes
    [driveMonitor.py]
2021-12-22 now reboots when the usb drive is removed, its a workaround for now since dev mapper will allow data to still be written after the disk is removed
    [driveMonitor.py]
2021-12-23 fixing detecting usb drive getting plugged in
    [driveMonitor.py]
2021-12-29 adding electron setup, still needs work but should setup the encryped device
2021-12-29 fix ssh error false error when waiting for reboot
    [setupkey_pt2.py]
2022-01-02 adding warning button, check for usb drive
2022-01-13 add sleep for bigger drives, add starting up another dropbear on port 2222 when the drive is mounted
2022-01-25 fixing slow drive mounting saying there's no container
    [driveMonitor.py]
2022-01-27 adding case
    [vented case with 3 hooks.stl]
2022-02-01 case with larger vents
    [vented case with 3 hooks.stl]
2022-02-04 reverting my boneheaded enum removal
    [driveMonitor.py]
2022-02-04 first stab at a case with vertical hooks
    [vented case with 3 vertical hooks.stl]
2022-02-09 adding status leds
2022-03-19 updated hollow case
    [vented case with 3 vertical hooks.stl]
2022-06-16 Update README.md
    adding a first stab at getting the raspberry pi steps setup.
2022-06-16 Add files via upload
    adding first attempt at a raspberry pi case
    [raspberry_pi_case.stl]
2022-06-16 Add files via upload
    adding assembly pics for raspberry pi
2022-06-16 Update README.md
    add link to raspberry pi case
